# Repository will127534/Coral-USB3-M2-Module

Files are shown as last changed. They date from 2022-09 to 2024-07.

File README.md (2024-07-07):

# Coral M.2 Module with USB3 connection with Host

Basically this is a 2242 M.2 Module with VL805 PCIe to USB3 controller connected to Google Coral Module via USB3, because Google Coral TPU still has some issue with the PCIe Driver on Raspberry Pi 4 as of 2022/09.


PCB designed with KiCad v6.0

More details (Blog post?) here: [Coral USB3 M2 Module](https://www.willwhang.dev/coral-USB3-M2-Module/)

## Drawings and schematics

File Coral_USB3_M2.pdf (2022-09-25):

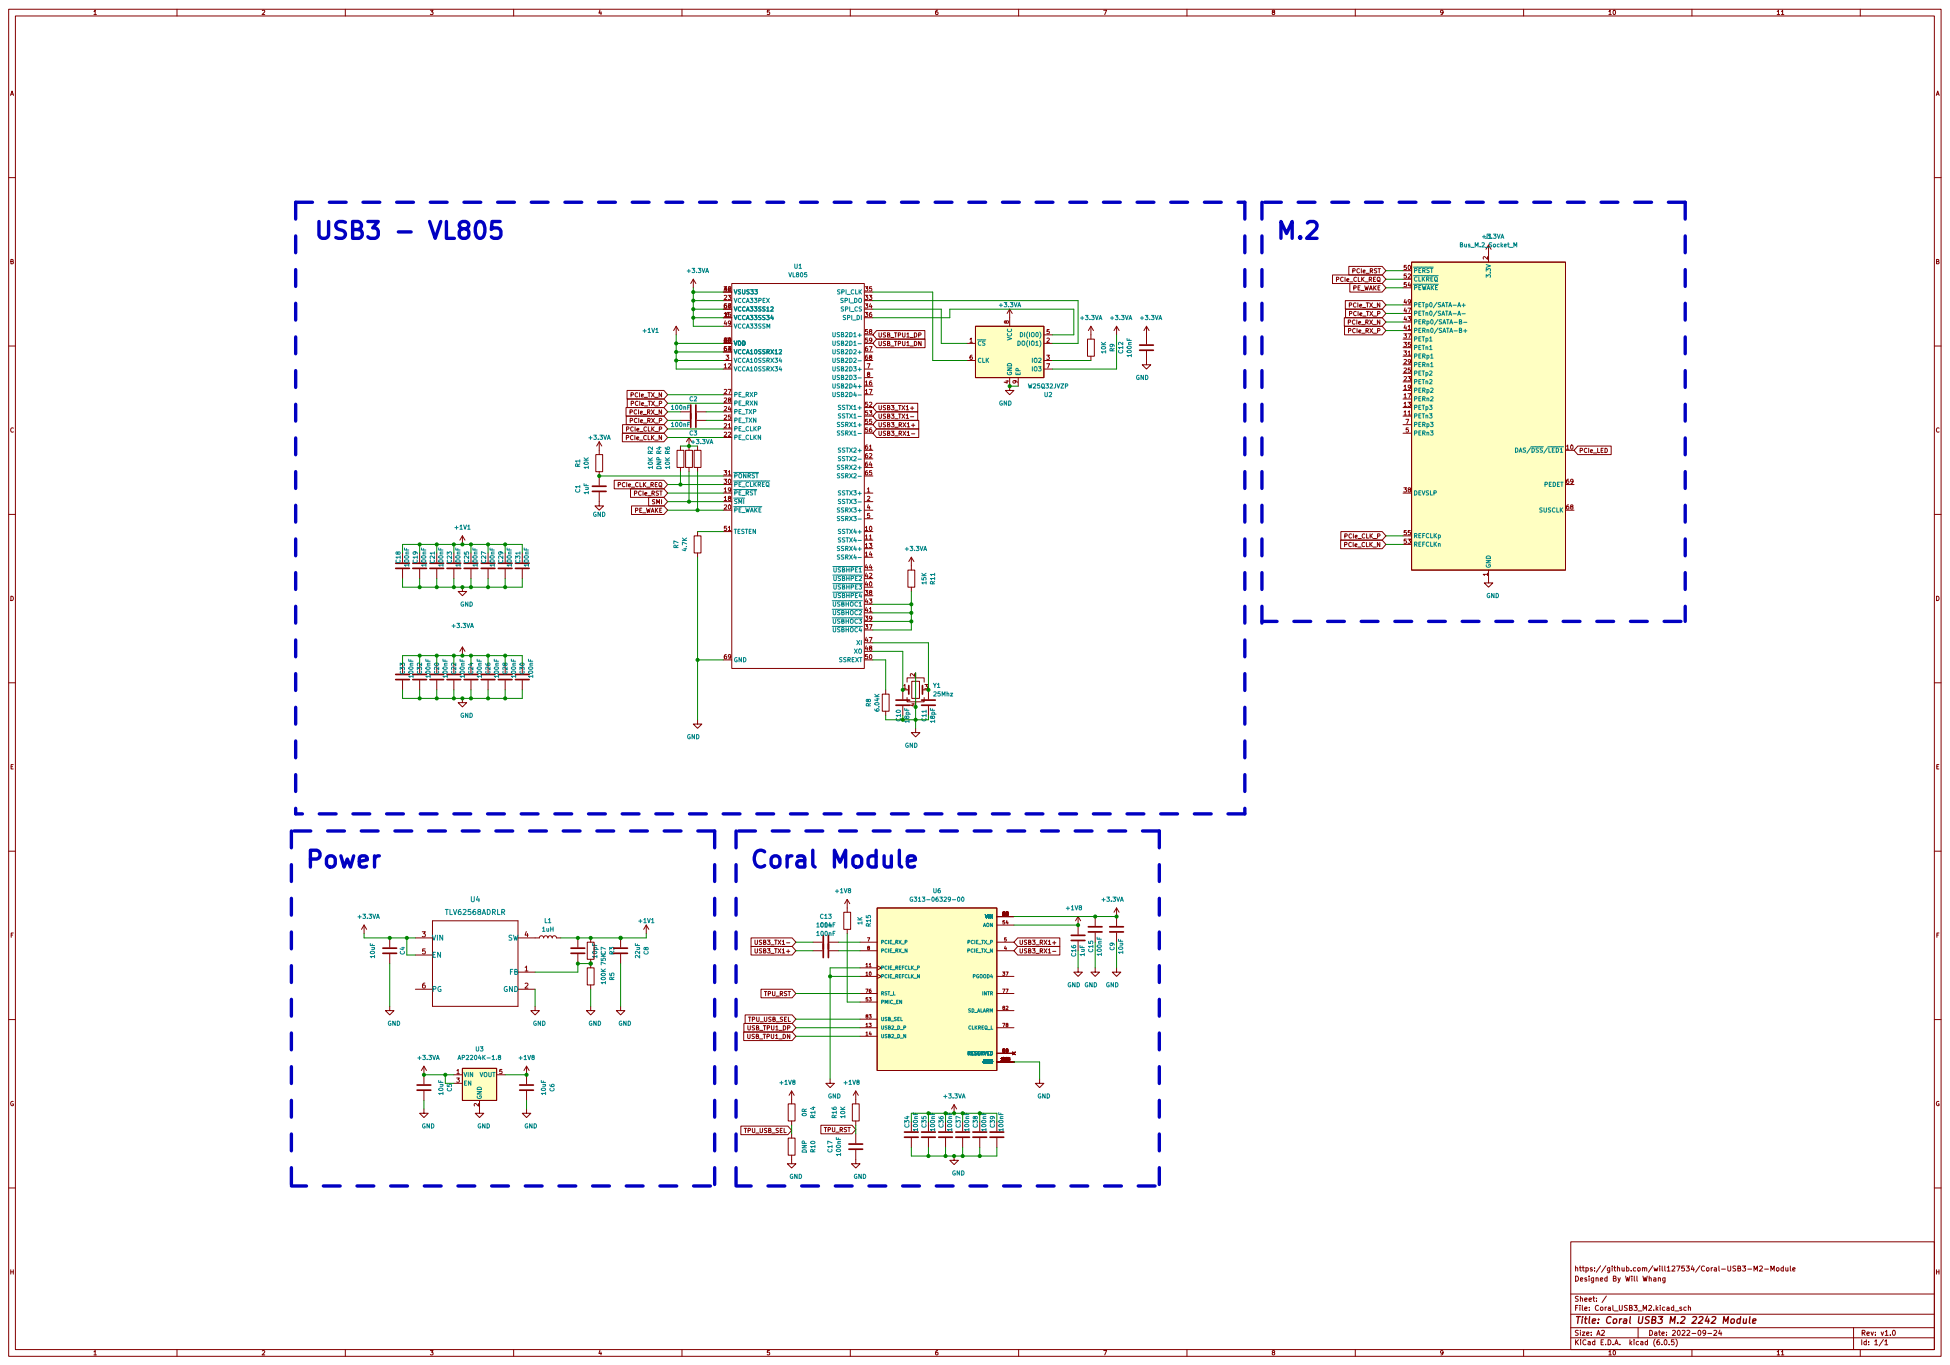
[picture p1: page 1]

2 EN 3 VOUT 5 U3 AP2204K-1.8 GND GND C5 10uF

File: Coral_USB3_M2.kicad_sch Sheet: / Designed By Will Whang

Id: 1/1 Title: Coral USB3 M.2 2242 Module

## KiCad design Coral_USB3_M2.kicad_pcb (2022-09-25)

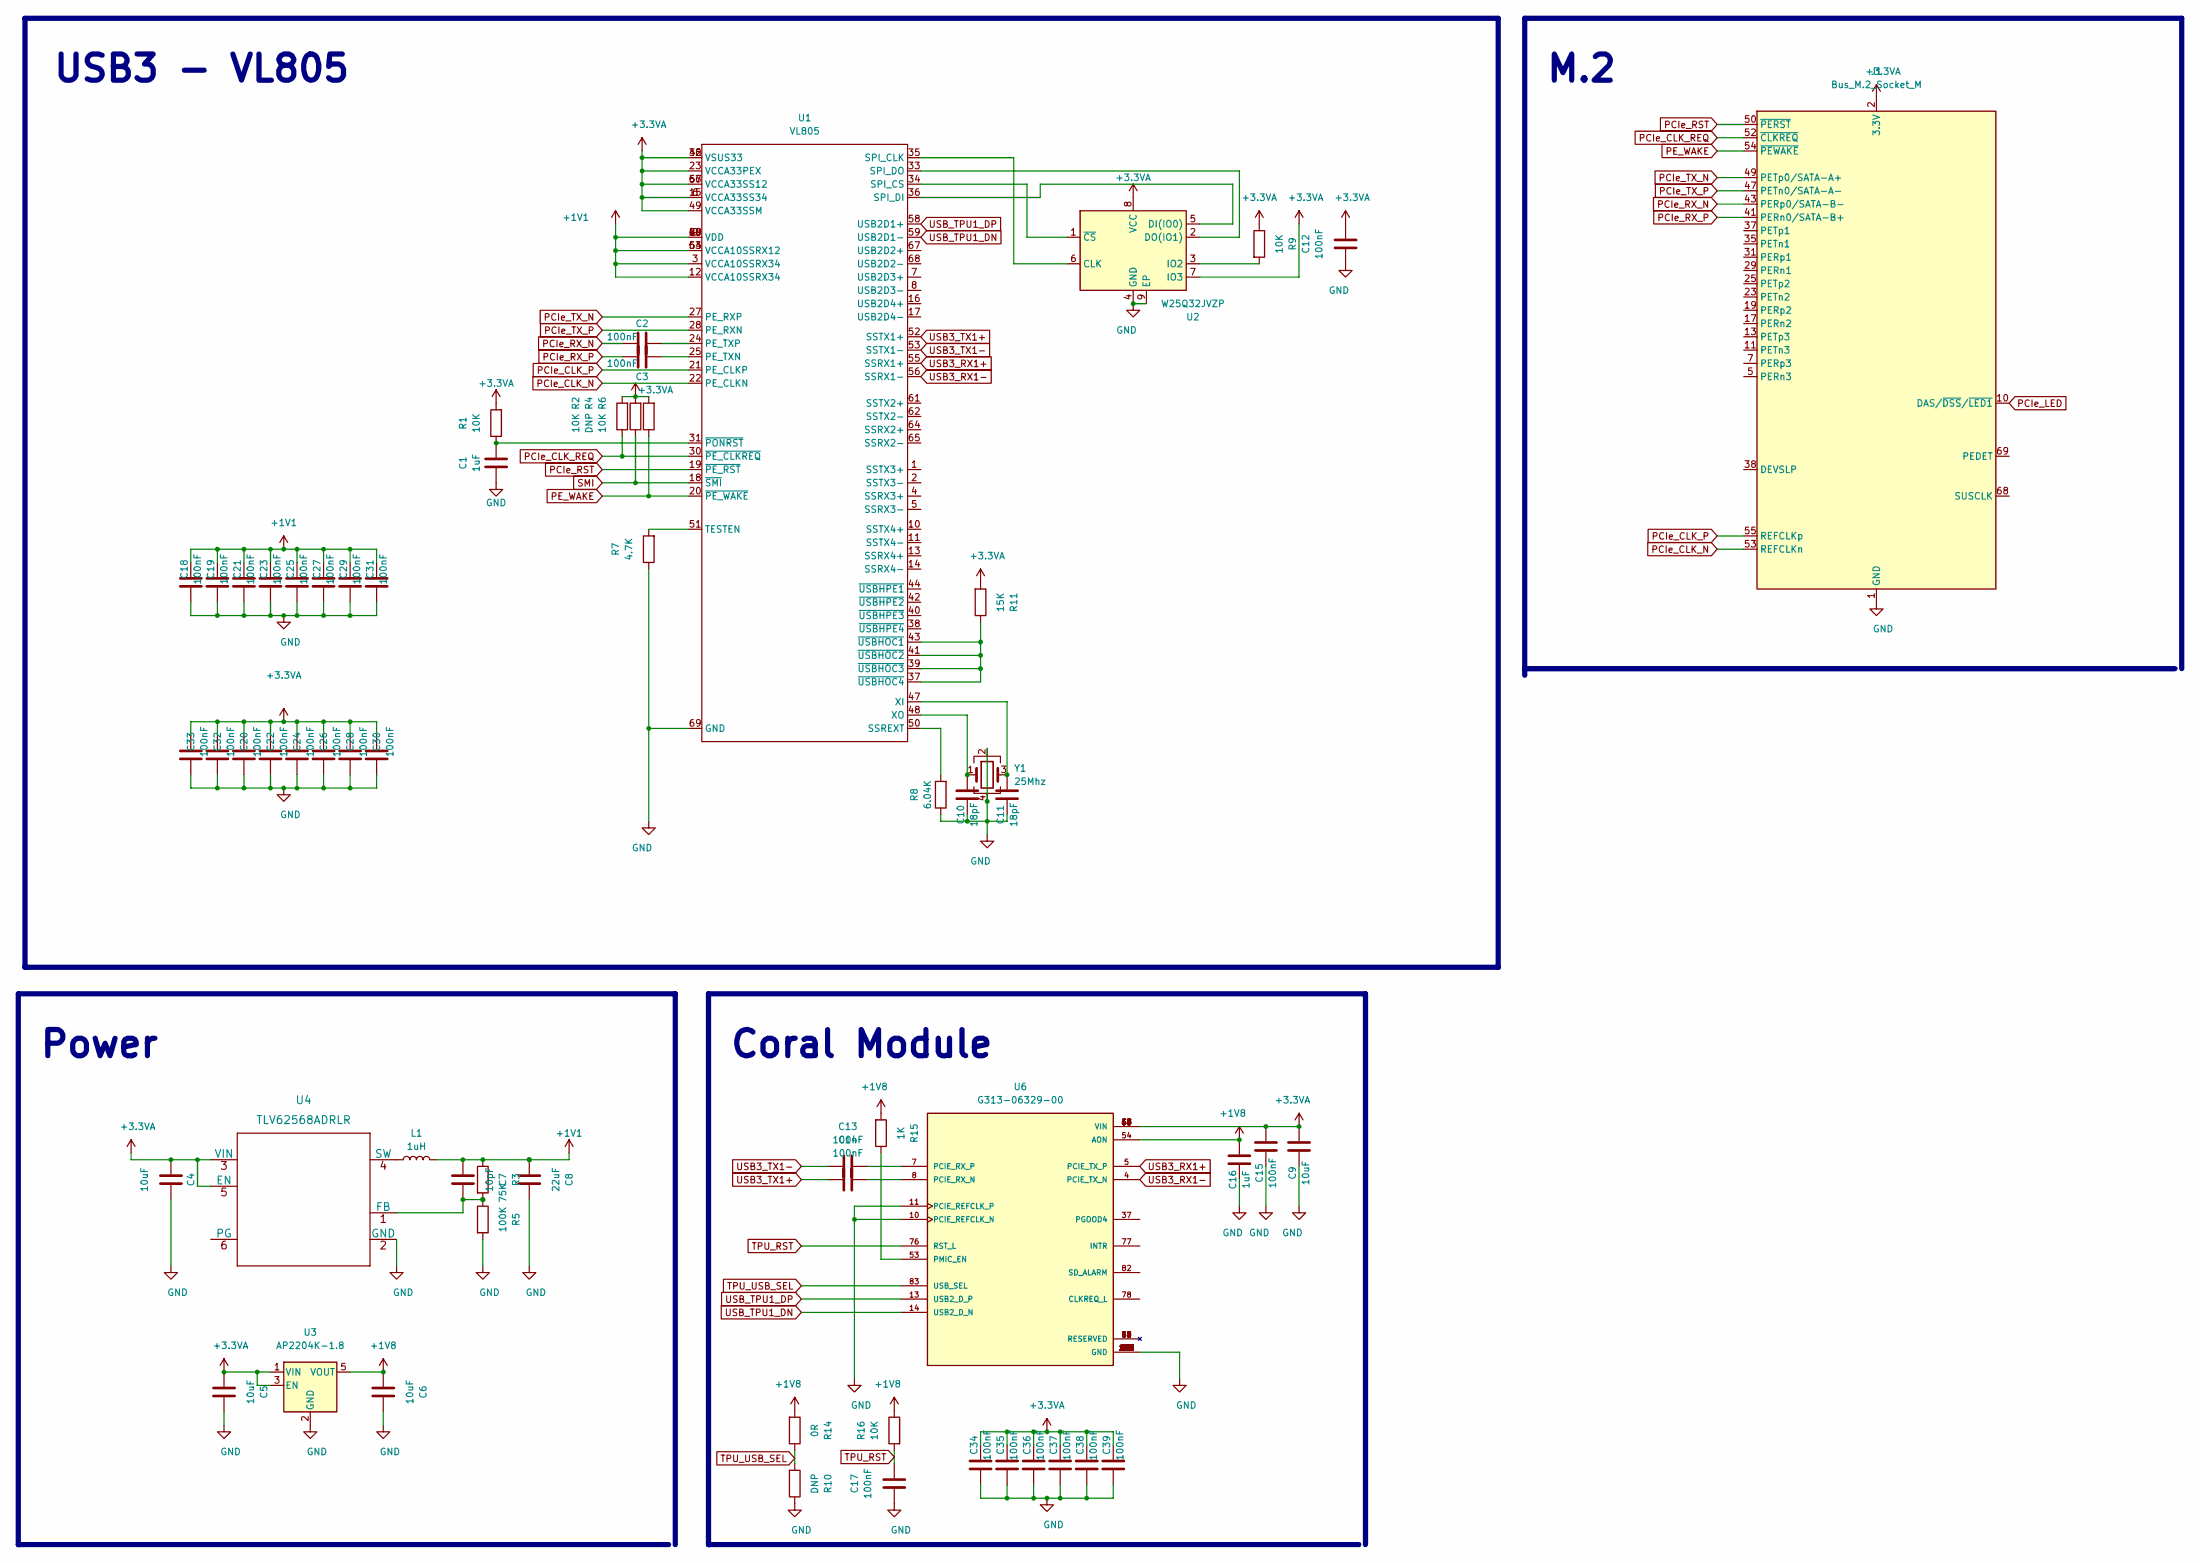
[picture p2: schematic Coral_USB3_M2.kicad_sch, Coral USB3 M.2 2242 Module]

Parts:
C1, C16: 1uF; C_0402_1005Metric
C2, C3, C12, C13, C14, C15, C17, C18, C19, C20, C21, C22, C23, C24, C25, C26, C27, C28, C29, C30, C31, C32, C33, C34, C35, C36, C37, C38, C39: 100nF; C_0402_1005Metric
C4: 10uF; C_0603_1608Metric
C5, C6, C9: 10uF; C_0402_1005Metric
C7: 10pF; C_0402_1005Metric
C8: 22uF; C_0603_1608Metric
C10, C11: 18pF; C_0402_1005Metric
J1: Bus_M.2_Socket_M; NGFF_M
L1: 1uH; L_Vishay_IHLP-1212
R1, R2, R6, R9, R16: 10K; R_0402_1005Metric
R3: 75K; R_0402_1005Metric
R4, R10: DNP; R_0402_1005Metric
R5: 100K; R_0402_1005Metric
R7: 4.7K; R_0402_1005Metric
R8: 6.04K; R_0402_1005Metric
R11: 15K; R_0402_1005Metric
R14: 0R; R_0402_1005Metric
R15: 1K; R_0402_1005Metric
U1: VL805; QFN-68-1EP_8x8mm_P0.4mm_EP5.2x5.2mm
U2: W25Q32JVZP; DFN-8-1EP_3x2mm_P0.5mm_EP1.36x1.46mm
U3: AP2204K-1.8; SOT-23-5
U4: TLV62568ADRLR; SOT-563
U6: G313-06329-00; MODULE_G313-06329-00; PARTREV 1.3
Y1: 25Mhz; Crystal_SMD_3225-4Pin_3.2x2.5mm

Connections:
+1V1: C7.1, C8.1, C18.2, C19.2, C21.2, C23.2, C25.2, C27.2, C29.2, C31.2, L1.2, R3.1, U1.3 (VCCA10SSRX34), U1.9 (VDD), U1.12 (VCCA10SSRX34), U1.29 (VDD), U1.45 (VDD), U1.54 (VCCA10SSRX12), U1.60 (VDD), U1.63 (VCCA10SSRX12)
+1V8: C6.1, C16.1, R14.2, R15.2, R16.1, U3.5 (VOUT), U6.54 (AON)
+3.3VA: C4.2, C5.1, C9.1, C12.2, C15.1, C20.2, C22.2, C24.2, C26.2, C28.2, C30.2, C32.2, C33.2, C34.2, C35.2, C36.2, C37.2, C38.2, C39.2, J1.2 (3.3V), J1.4 (3.3V), J1.12 (3.3V), J1.14 (3.3V), J1.16 (3.3V), J1.18 (3.3V), J1.70 (3.3V), J1.72 (3.3V), J1.74 (3.3V), R1.2, R2.2, R4.2, R6.2, R9.1, R11.2, U1.6 (VCCA33SS34), U1.15 (VCCA33SS34), U1.23 (VCCA33PEX), U1.32 (VSUS33), U1.46 (VSUS33), U1.49 (VCCA33SSM), U1.57 (VCCA33SS12), U1.66 (VCCA33SS12), U2.7 (IO3), U2.8 (VCC), U3.1 (VIN), U3.3 (EN), U4.3 (VIN), U4.5 (EN), U6.56 (VIN), U6.57 (VIN), U6.58 (VIN), U6.59 (VIN), U6.60 (VIN), U6.61 (VIN), U6.62 (VIN), U6.63 (VIN), U6.64 (VIN), U6.65 (VIN), U6.66 (VIN), U6.67 (VIN)
GND: C1.1, C4.1, C5.2, C6.2, C8.2, C9.2, C10.1, C11.1, C12.1, C15.2, C16.2, C17.2, C18.1, C19.1, C20.1, C21.1, C22.1, C23.1, C24.1, C25.1, C26.1, C27.1, C28.1, C29.1, C30.1, C31.1, C32.1, C33.1, C34.1, C35.1, C36.1, C37.1, C38.1, C39.1, J1.1 (GND), J1.3 (GND), J1.9 (GND), J1.15 (GND), J1.21 (GND), J1.27 (GND), J1.33 (GND), J1.39 (GND), J1.45 (GND), J1.51 (GND), J1.57 (GND), J1.71 (GND), J1.73 (GND), J1.75 (GND), R5.2, R7.1, R8.1, R10.1, U1.69 (GND), U2.4 (GND), U2.9 (EP), U3.2 (GND), U4.2 (GND), U6.1 (GND), U6.2 (GND), U6.3 (GND), U6.6 (GND), U6.9 (GND), U6.10 (PCIE_REFCLK_N), U6.11 (PCIE_REFCLK_P), U6.12 (GND), U6.15 (GND), U6.16 (GND), U6.17 (GND), U6.18 (GND), U6.19 (GND), U6.20 (GND), U6.21 (GND), U6.22 (GND), U6.23 (GND), U6.24 (GND), U6.25 (GND), U6.26 (GND), U6.27 (GND), U6.28 (GND), U6.29 (GND), U6.30 (GND), U6.31 (GND), U6.32 (GND), U6.33 (GND), U6.34 (GND), U6.35 (GND), U6.36 (GND), U6.38 (GND), U6.39 (GND), U6.40 (GND), U6.41 (GND), U6.42 (GND), U6.43 (GND), U6.44 (GND), U6.45 (GND), U6.46 (GND), U6.47 (GND), U6.48 (GND), U6.51 (GND), U6.55 (GND), U6.68 (GND), U6.69 (GND), U6.70 (GND), U6.71 (GND), U6.72 (GND), U6.73 (GND), U6.74 (GND), U6.75 (GND), U6.79 (GND), U6.80 (GND), U6.81 (GND), U6.86 (GND), U6.87 (GND), U6.88 (GND), U6.89 (GND), U6.90 (GND), U6.91 (GND), U6.92 (GND), U6.93 (GND), U6.94 (GND), U6.95 (GND), U6.96 (GND), U6.97 (GND), U6.98 (GND), U6.99 (GND), U6.100 (GND), U6.101 (GND), U6.102 (GND), U6.103 (GND), U6.104 (GND), U6.105 (GND), U6.106 (GND), U6.107 (GND), U6.108 (GND), U6.109 (GND), U6.110 (GND), U6.111 (GND), U6.112 (GND), U6.113 (GND), U6.114 (GND), U6.115 (GND), U6.116 (GND), U6.117 (GND), U6.118 (GND), U6.119 (GND), U6.120 (GND), Y1.2, Y1.4
unnamed: C1.2, R1.1, U1.31 (~PONRST)
unnamed: C2.2, U1.24 (PE_TXP)
unnamed: C3.2, U1.25 (PE_TXN)
unnamed: C7.2, R3.2, R5.1, U4.1 (FB)
unnamed: C10.2, U1.48 (XO), Y1.1
unnamed: C11.2, U1.47 (XI), Y1.3
unnamed: C13.2, U6.7 (PCIE_RX_P)
unnamed: C14.2, U6.8 (PCIE_RX_N)
unnamed: L1.1, U4.4 (SW)
unnamed: R7.2, U1.51 (TESTEN)
unnamed: R8.2, U1.50 (SSREXT)
unnamed: R9.2, U2.3 (IO2)
unnamed: R11.1, U1.37 (~USBHOC4), U1.39 (~USBHOC3), U1.41 (~USBHOC2), U1.43 (~USBHOC1)
unnamed: R15.1, U6.53 (PMIC_EN)
unnamed: U1.33 (SPI_DO), U2.2 (DO(IO1))
unnamed: U1.34 (SPI_CS), U2.1 (~CS)
unnamed: U1.35 (SPI_CLK), U2.6 (CLK)
unnamed: U1.36 (SPI_DI), U2.5 (DI(IO0))
PCIe_CLK_N: J1.53 (REFCLKn), U1.22 (PE_CLKN)
PCIe_CLK_P: J1.55 (REFCLKp), U1.21 (PE_CLKP)
PCIe_CLK_REQ: J1.52 (~CLKREQ), R2.1, U1.30 (~PE_CLKREQ)
PCIe_LED: J1.10 (DAS/~DSS/~LED1)
PCIe_RST: J1.50 (~PERST), U1.19 (~PE_RST)
PCIe_RX_N: C2.1, J1.43 (PERp0/SATA-B-)
PCIe_RX_P: C3.1, J1.41 (PERn0/SATA-B+)
PCIe_TX_N: J1.49 (PETp0/SATA-A+), U1.27 (PE_RXP)
PCIe_TX_P: J1.47 (PETn0/SATA-A-), U1.28 (PE_RXN)
PE_WAKE: J1.54 (~PEWAKE), R6.1, U1.20 (~PE_WAKE)
SMI: R4.1, U1.18 (~SMI)
TPU_RST: C17.1, R16.2, U6.76 (RST_L)
TPU_USB_SEL: R10.2, R14.1, U6.83 (USB_SEL)
USB3_RX1+: U1.55 (SSRX1+), U6.5 (PCIE_TX_P)
USB3_RX1-: U1.56 (SSRX1-), U6.4 (PCIE_TX_N)
USB3_TX1+: C14.1, U1.52 (SSTX1+)
USB3_TX1-: C13.1, U1.53 (SSTX1-)
USB_TPU1_DN: U1.59 (USB2D1-), U6.14 (USB2_D_N)
USB_TPU1_DP: U1.58 (USB2D1+), U6.13 (USB2_D_P)

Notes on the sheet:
Power
M.2
Coral Module
USB3 - VL805

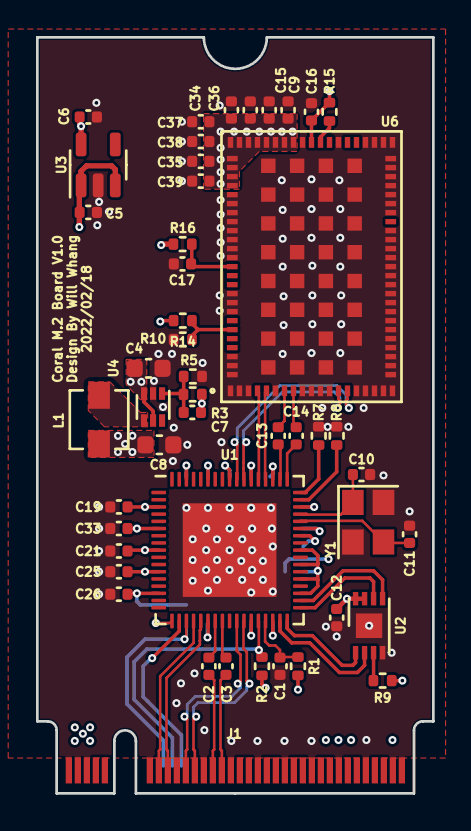
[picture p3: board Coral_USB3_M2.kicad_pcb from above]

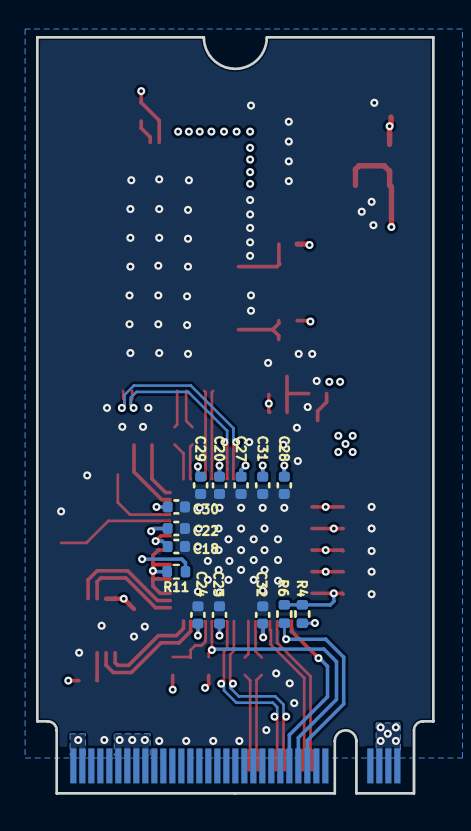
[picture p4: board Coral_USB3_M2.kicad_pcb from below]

Board: 4 copper layers, 22.0 x 42.0 mm, 61 parts (14 on the bottom side), 40 nets.

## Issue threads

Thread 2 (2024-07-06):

USB 3 operation

phodina, 2024-07-06:
Hi @will127534 ,

so in order to get the USB 3 mode operation it's necessary to use PCIe to USB converter? There's no way to use the diff pairs directly and connect them straight to USB signals?

Is this the way how they do it on the consumer products such as the Coral USB module?

https://gitlab.com/phodina/coral-bay

phodina, 2024-07-07:
Also what about the impedence matching? Guess the same for PCIe applies to USB signals, right?

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

will127534, 2024-07-07:
Have you checked the blog post about the project?

phodina, 2024-07-07:
Have done that know. The link is broken. Fix in MR. https://github.com/will127534/Coral-USB3-M2-Module/pull/3

Yes, you explain that the PCIe diff pairs  can be used as USB 3 RX and TX pairs.

And as you use the M.2 module for Coral <-> USB 3 <-> VL805 <-> PCIe I can just use it directly.

Haven't checked the lengths in the PCB of the project but I guess the lines are tuned as required by the datasheet.

will127534, 2024-07-07:
Thanks,

However I don't recommend you use Coral module for Framework Laptops, just pure CPU power should already be more then what Coral module can deliver, while iGPUs on shipping laptops can blow Coral module away on computing power and it is way easier to deploy ML models.

Don't waste your time on Coral module, it is an age old products without any updates.

Closed 2024-07-07.
